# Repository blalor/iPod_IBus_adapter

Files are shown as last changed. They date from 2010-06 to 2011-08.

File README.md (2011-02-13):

iPod ↔ Sirius IBus adapter
==========================

This project is an Arduino sketch that presents an iPod or iPhone as a Sirius satellite radio receiver to the head unit (radio) in some MINI and BMW models.  It supports both simple and advanced iPod protocols.  In advanced mode, the radio shows the current track name as the channel text, and artist and album are accessible via the `INF` button.

I originally started this project because I wanted to put the radio from an '06 MINI into my '91 BMW 318is.  The MINI radio must see a valid IBus message in order to operate, otherwise it displays `-DISABLE-` on the screen and doesn't do anything at all.  Spitting out a valid IBus message every now and then would be simple.  But then I realized that iPod adapters (like the Dension ice>Link:Plus I have in my MINI) aren't cheap and most don't do everything I want, so I decided to keep going.

The end result is pretty much what I was going for, but there are some bugs to be worked out.

For more info, see the [Wiki](https://github.com/blalor/iPod_IBus_adapter/wiki/)

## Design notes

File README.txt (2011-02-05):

http://docs.hp.com/en/B3901-90007/ch05s09.html
http://www.nongnu.org/avr-libc/user-manual/group__util__setbaud.html
http://en.wikipedia.org/wiki/Circular_buffer
http://en.wikipedia.org/wiki/Operators_in_C_and_C%2B%2B
http://en.wikipedia.org/wiki/Modulo_operation

The structure of an Ibus packet is the following :
 -	Source Device ID The device which needs to send a message to another device
 -	Length The length of the packet whithout Source ID and length it-self.
 -	Destination Device ID The device which must receive the message
 -	Data The message to send to Destination ID
 -	XOR CheckSum This byte is used to check the integrity of the message. 
         The receiver will compare that value with its own computation, and
         if not equal, will reject the packet.

Messages we understand:
    src: 0x68 (radio)
        dest: 0x73 (satellite radio)
    
            cmd: 0x01 — "are you there" from radio; sent every 10s or so
            cmd: 0x3D
                data byte 1:
                    0x00 — power @todo
                    0x01 — mode @todo
                    0x02 — now @todo
                    0x03 — channel up
                    0x04 — channel down
                    0x05 — channel up and hold
                    0x06 — channel down and hold
            
                    0x08 — preset button pressed
                    0x09 — preset button press and hold
                        data byte 2 is preset number (0x01, 0x02, … 0x06)
            
                    0x0D — "m" @todo
                
                    0x0E — INF (press?) @todo
                    0x0F — INF (press and hold?) @todo
                        may need to ack 0x0E before we get 0x0F
            
                    0x14 — SAT pressed and held
                    0x15 — SAT pressed

Messages we send:
    src: 0x73 (satellite radio)
        dest: 0x68 (radio)
            data: 0x02 0x00 — poll response (sent for "are you there" from radio)
            data: 0x02 0x01 — announcement when bus activates
    
        dest: 0x68
            data byte 1: 0x3E
                all follow format
                    0x3E xx yy CC BP zz .. .. .. ..
                where:
                    xx yy — sub-command bytes
                    CC    — channel
                    B     — band nibble
                    P     — preset nibble (0-6)
                    zz    — command end byte (no idea, really)
                    ..    — text
                
                0x00 0x00 CC BP 04
                    response to power, mode
                
                // what is the 2nd byte? 0x00, 0x06, 0x07
                0x01 0x00 CC BP 04 ..
                    send text to show on head unit
                    limit of 8 or 9 characters. does not need to be refreshed
                    until it changes (I think)
                
                0x01 0x06 CC 01 01 ..
                    ack INF press. note diff't end byte, band 0, preset 1
                
                0x01 0x07 CC 01 01 ..
                    ack INF2 press. note diff't end byte, band 0, preset 1
                
                0x02 0x00 CC BP 04 '        '
                    response to channel up/down, "what now", preset and sat
                    button presses; text sent is 8 spaces

Button presses and interactions that cause ACQUIRING to (re)appear
    • pressing SAT

Other observances:
    • holding "M" seems to force a "now" command, but a single press of "M" does nothing

characters:
    ~ == ->
 \x7f == <-

== 10/14/2010 ==
so, basically "now" equates to stopping a long-running button press, and/or asking for a status update.

questions for Josh's setup:
• what does the SDRS transmit on startup?
• … when the radio is powering off (if anything(?))
• … when the radio switches modes (if anything(?))
• … in response to "now"?

• verify button presses above

• what does a single "M" push do? -- nothing
• … and does it change the operation of any other buttons? -- no
• what does a single "SAT" press do? -- changes preset bank

• what sequence of commands is sent after a channel change?
• … after an ESN request (hold "sat")

• how change band (actually, preset bank)? -- sat

mini-din 8 pinout:
1 — ipod_txd (from ipod to µC)
2 — ipod_rxd_3v3 (from µC to to ipod @ 3.3v)
3 — +5v
4 — n/c
5 — gnd
6 — line_out_r
7 — audio_gnd
8 — line_out_l

ipod connector board pinout:
1 — audio_gnd
2 — right_out
3 — left_out
4 — ipod_tx
5 — ipod_rx
6 — vcc (+5v)
7 — gnd

signal | ipod | DIN | color
-------+------+-----+--------
a_gnd  |   1  |  7  | blue
right  |   2  |  6  | green
left   |   3  |  8  | violet
txd    |   4  |  1  | black
rxd    |   5  |  2  | brown
vcc    |   6  |  3  | red
gnd    |   7  |  5  | yellow

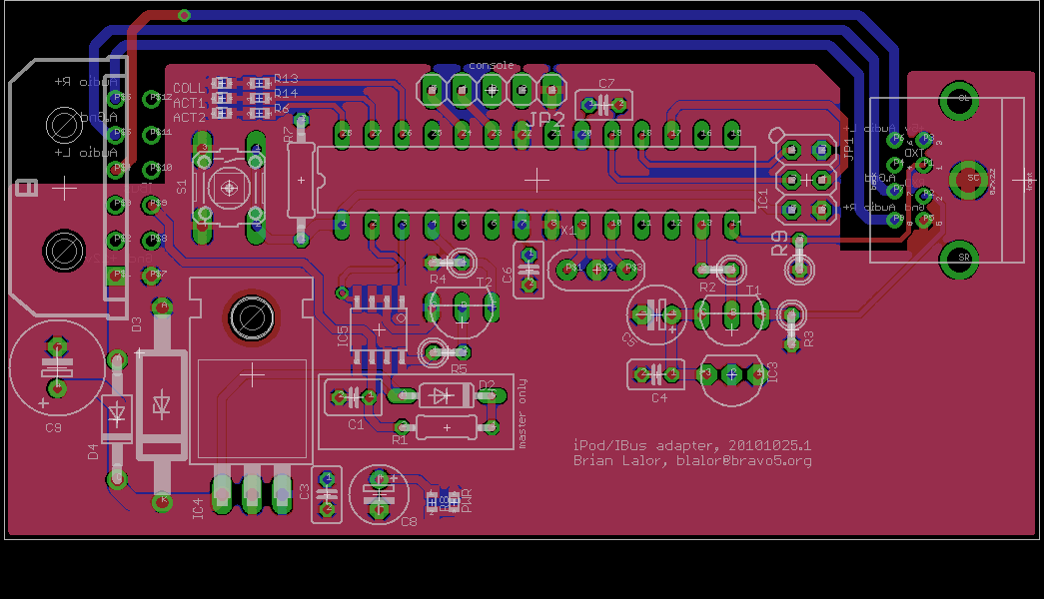
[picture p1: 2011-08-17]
eagle/ibus_adapter.brd.png

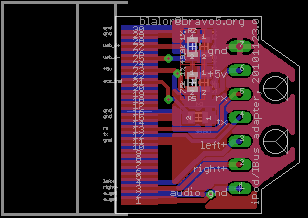
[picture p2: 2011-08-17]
eagle/ipod_connector.brd.png

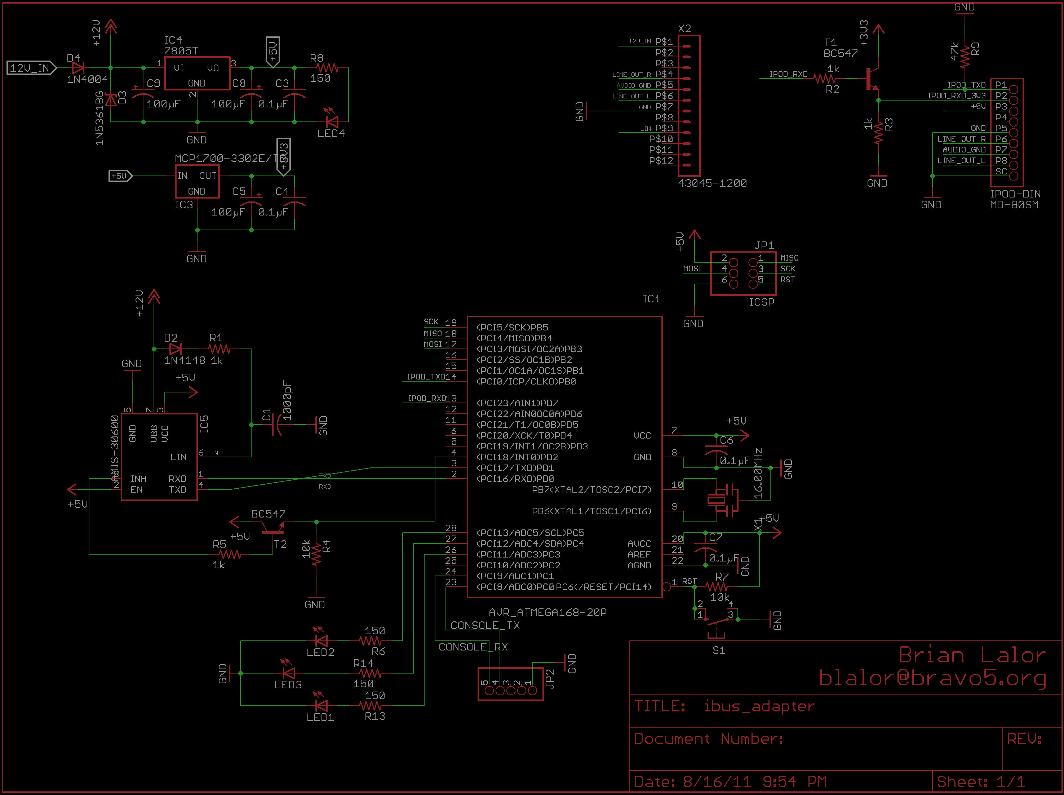
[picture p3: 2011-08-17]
eagle/ibus_adapter.sch.png

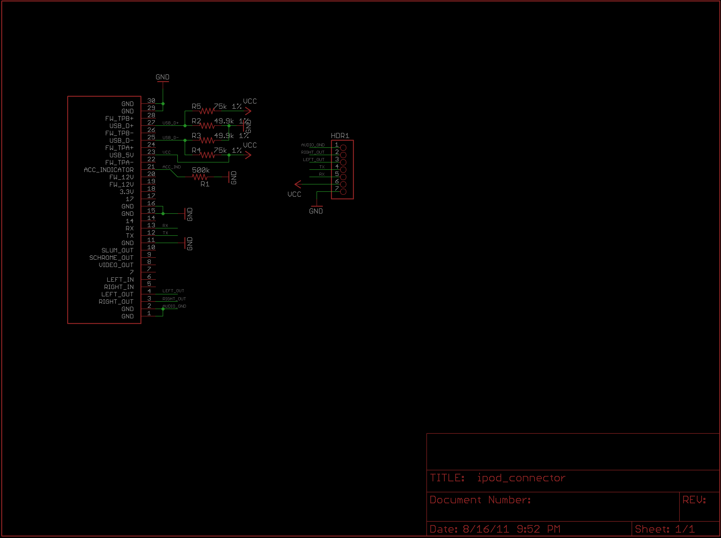
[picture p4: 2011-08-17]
eagle/ipod_connector.sch.png

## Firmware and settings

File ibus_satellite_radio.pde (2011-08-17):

/*
    The default state for an iPod when it's connected to this adapter is in
    "simple" mode; it should revert to this state whenever it's disconnected.
    
    Outstanding issues:
    • need to deal with millis() rollover
    • iPod still stops responding, occasionally
    • occasionally doesn't get metadata after iPod reconnect
    • still shows garbage at end of metadata strings after startup
    
    Current status: iPod operation appears reliable on my workbench and in the
    BMW.
 */
#define DEBUG 0
#define DEBUG_PACKET_PARSING 0
#define WICKED_VERBOSE 0

#include <string.h>
#include <stdlib.h>
#include <stdio.h>

#include <avr/wdt.h>

#include <SoftwareSerial.h>

// this is to make the Arduino include-path kludge-ifier work for iPodWrapper.h
#include <AdvancedRemote.h>

#include "iPodWrapper.h"
#include "pgm_util.h"

// @todo look into whether the preprocessor will magically convert 
// strlen("foo") -> 3
//    https://lists.linux-foundation.org/pipermail/openais/2010-March/014011.html
// … possibly; see the comment about strlen() in the section on the 
// "freestanding" compiler option:
//    http://www.nongnu.org/avr-libc/user-manual/using__tools.html#gcc_minusW
// sizeof() is compile-time?
//    http://www.avrfreaks.net/index.php?name=PNphpBB2&file=viewtopic&t=32181&start=0
#define IBUS_DATA_END_MARKER() "\xAA\xBB"
#define ibus_data(_DATA) PSTR((_DATA IBUS_DATA_END_MARKER()))

const char *IBUS_DATA_END_MARKER = IBUS_DATA_END_MARKER();

// pin mappings
#define INH_PIN 2

// RX for console is not currently supported; need special handling for
// multiple SoftwareSerial instances
#define CONSOLE_RX_PIN 14
#define CONSOLE_TX_PIN 15

#define IPOD_RX_PIN 8 // 14 on chip
#define IPOD_TX_PIN 7 // 13 on chip

/*
 * LEDs:
 *   red: missed poll from radio
 *   yellow: processing incoming IBus data
 *   green: sending IBus data
 *   
 *   yellow + green: contention/collision when sending
 */
#define LED_ERR      19 // red
#define LED_IBUS_RX  18 // yellow
#define LED_IBUS_TX  17 // green

// addresses of IBus devices
#define RAD_ADDR  0x68
#define SDRS_ADDR 0x73

// static offsets into the packet
#define PKT_SRC  0
#define PKT_LEN  1
#define PKT_DEST 2
#define PKT_CMD  3

// SDRS commands
#define SDRS_CMD_POWER          0x00 // power; not seen in Josh's car
#define SDRS_CMD_MODE           0x01 // mode
#define SDRS_CMD_NOW            0x02 // "now"
#define SDRS_CMD_CHAN_UP        0x03 // channel up
#define SDRS_CMD_CHAN_DOWN      0x04 // channel down
#define SDRS_CMD_CHAN_UP_HOLD   0x05 // channel up and hold
#define SDRS_CMD_CHAN_DOWN_HOLD 0x06 // channel down and hold
#define SDRS_CMD_START_SCAN     0x07 // "M" down and hold; start scan
#define SDRS_CMD_PRESET         0x08 // preset recall
#define SDRS_CMD_PRESET_HOLD    0x09 // preset store
#define SDRS_CMD_INF1           0x0E // INF 1st press; display artist
#define SDRS_CMD_INF2           0x0F // INF 2nd press; display song
#define SDRS_CMD_ESN_REQ        0x14 // SAT press and hold; ESN request
#define SDRS_CMD_SAT            0x15 // SAT press; preset bank change

// there may well be a protocol-imposed limit to the max value of a length
// byte in a packet, but it looks like this is the biggest we'll see in
// practice.  Use this as a sort of heuristic to determine if the incoming
// data is valid.
#define MAX_EXPECTED_LEN 64

#if MAX_EXPECTED_LEN > RX_BUFFER_SIZE
    #error MAX_EXPECTED_LEN bigger than RX_BUFFER_SIZE in HardwareSerial.h
#endif

#define TX_BUF_LEN 80
#define RX_BUF_LEN (MAX_EXPECTED_LEN + 2)

/*
prescale    target timer count  rounded timer count       (D)    (E)          % diff
       1             11110.111                11110     1440    1440.0144    -0.0010
       8              1387.888                 1388     1440    1439.8848     0.0079
      32               346.222                  346     1440    1440.9221    -0.0640
      64               172.611                  173     1440    1436.7816     0.2234
     128                85.805                   86     1440    1436.7816     0.2234
     256                42.402                   42     1440    1453.4883    -0.9366
    1024                 9.850                   10     1440    1420.4545     1.3573

@ todo
to detect the line being idle for 1.5 byte periods:
    9600-8-e-1 => 11 bits/byte
    11 * 1.5 = 16.5 bit periods

target timer count=((16000000/A2)/(960*1.5))-1 [((16000000/1)/(9600*11*1.5))-1]
rounded timer count=ROUND(target timer count '1', 0)
(D)=(16000000/A2)/(target timer count '1'+1)
(E)=(16000000/A2)/(rounded timer count '1'+1)
% diff=100-(E2*100)/D2
*/
#define CONTENTION_TIMEOUT 173        

// buffer for building outgoing packets
uint8_t tx_buf[TX_BUF_LEN];

// buffer for processing incoming packets; same size as serial buffer
uint8_t rx_buf[RX_BUF_LEN];

typedef enum __sdrs_status_enum {
    SDRS_STATUS_UNKNOWN,
    SDRS_STATUS_INACTIVE,
    SDRS_STATUS_ACTIVE
} SDRSStatusEnum;

typedef struct __sat_state {
    uint8_t channel;
    uint8_t presetBank;
    uint8_t presetNum;
    SDRSStatusEnum status; // whether we're playing or not
    boolean scanning;
} SatState;

SatState satelliteState = {1, 1, 0, SDRS_STATUS_UNKNOWN, false};

/*
 * time-keeping variables
 */
// timestamp of last poll from radio
unsigned long lastPoll; // 20s timeout

// trigger time to turn off LED
unsigned long ledOffTime; // 500ms interval

// timeout duration before giving up on a read
unsigned long readTimeout; // variable

#if DEBUG
    unsigned long lastFreeMemCheck; // 10s, or more frequently
#endif /* DEBUG */

// the 47k pull-down on the RX pin allows the iPodWrapper to detect the 
// presence of the iPod
SoftwareSerial nssIPod(
    IPOD_RX_PIN, // RX pin
    IPOD_TX_PIN, // TX pin
    false,       // inverse_logic
    false,       // disable_rx
    true         // disable_pullup
);

#if DEBUG
    SoftwareSerial nssConsole(CONSOLE_RX_PIN, CONSOLE_TX_PIN);
#endif

IPodWrapper iPodWrapper;
IPodWrapper::IPodPlayingState iPodPlayState;

// only 8 chars show on the screen for the channel display. It doesn't scroll
// on its own.
#define CHANNEL_TEXT_LENGTH 8
char channel_text_data[CHANNEL_TEXT_LENGTH + 1];
volatile boolean bus_inhibited;
boolean announcement_sent;

// this'll give me flexibility to swap between soft- and hard-ware serial 
// while developing
Print *console;

// http://www.nongnu.org/avr-libc/user-manual/group__avr__watchdog.html#_details
// http://www.nongnu.org/avr-libc/user-manual/FAQ.html#faq_startup
// http://www.nongnu.org/avr-libc/user-manual/group__largedemo.html#largedemo_code_p4
uint8_t mcusr_mirror __attribute__ ((section (".noinit")));

void get_mcusr_and_disable_wdt(void) \
  __attribute__((naked)) \
  __attribute__((section(".init3")));

void get_mcusr_and_disable_wdt(void) {
  mcusr_mirror = MCUSR;
  MCUSR = 0;
  
  wdt_disable();
}

// {{{ trackChangedHandler
void trackChangedHandler(unsigned long playlistPosition) {
    // iPod playlist position starts at 0; for aesthetics, we should start at 1
    satelliteState.channel = ((uint8_t) playlistPosition) + 1;
    update_sdrs_status();
}
// }}}

// {{{ metaDataChangedHandler
void metaDataChangedHandler() {
    update_sdrs_channel_text();
}
// }}}

// {{{ playStateChangedHandler
void playStateChangedHandler(IPodWrapper::IPodPlayingState playState) {
    // PLAY_STATE_UNKNOWN,
    // PLAY_STATE_PLAYING,
    // PLAY_STATE_PAUSED,
    // PLAY_STATE_STOPPED
    
    iPodPlayState = playState;
    
    update_sdrs_channel_text();
}
// }}}

// {{{ iPodModeChangedHandler
// for notification when mode changes between simple and advanced
void iPodModeChangedHandler(IPodWrapper::IPodMode mode) {
    // MODE_UNKNOWN,
    // MODE_SIMPLE,
    // MODE_ADVANCED

    #if DEBUG
        if (mode == IPodWrapper::MODE_UNKNOWN) {
            DEBUG_PGM_PRINTLN("[iPod] went away!");
        } else if (mode == IPodWrapper::MODE_SIMPLE) {
            DEBUG_PGM_PRINTLN("[iPod] switched to simple mode");
        } else if (mode == IPodWrapper::MODE_ADVANCED) {
            DEBUG_PGM_PRINTLN("[iPod] switched to advanced mode");
        }
    #endif
    
    update_sdrs_channel_text();
}
// }}}

#if DEBUG
    extern int __bss_end;
    extern int *__brkval;

    void printFreeMemory() {
        int free_mem;
        if ((int) __brkval == 0) {
            free_mem = ((int) &free_mem) - ((int) &__bss_end);
        } else {
            free_mem = ((int) &free_mem) - ((int)__brkval);
        }
    
        DEBUG_PGM_PRINT("free mem: ");
        DEBUG_PRINTLN(free_mem);
        lastFreeMemCheck = millis();
    }
#endif /* DEBUG */

// {{{ setup
void setup() {
    #if DEBUG
        // RX not supported; see comment near CONSOLE_RX_PIN define
        nssConsole.begin(115200);
        
        console = &nssConsole;
        
        printFreeMemory();
        
        if (mcusr_mirror & _BV(PORF))  DEBUG_PGM_PRINTLN("==== power-on reset ====");
        if (mcusr_mirror & _BV(EXTRF)) DEBUG_PGM_PRINTLN("==== external reset ====");
        if (mcusr_mirror & _BV(BORF))  DEBUG_PGM_PRINTLN("==== brown-out reset ====");
        if (mcusr_mirror & _BV(WDRF))  DEBUG_PGM_PRINTLN("==== watchdog reset ====");
    #endif /* DEBUG */
    
    pinMode(LED_ERR, OUTPUT);
    pinMode(LED_IBUS_TX, OUTPUT);
    pinMode(LED_IBUS_RX, OUTPUT);
    
    pinMode(INH_PIN, INPUT);
    
    // indicate setup is underway; green flashes for IBus TX
    digitalWrite(LED_IBUS_RX, HIGH);
    
    announcement_sent = false;
    
    // zero-out channel text buffer, including trailing nul
    memset(channel_text_data, 0, CHANNEL_TEXT_LENGTH + 1);
    
    // Set up timer2 at Fcpu/64 for contention detection. Must be done before 
    // any IBus serial activity!
    //     CS22:1, CS21:0, CS20:0
    TCCR2B = _BV(CS22); // ~_BV(CS21) | ~_BV(CS20);
    
    // set up serial for IBus; 9600,8,E,1
    Serial.begin(9600);
    UCSR0C |= _BV(UPM01); // even parity
    
    // start the watchdog timer w/ 4s timeout
    wdt_enable(WDTO_4S);

    // test to make sure the bus is alive; if it isn't, shut down (but do not
    // reconfigure) the USART
    
    if (digitalRead(INH_PIN) == LOW) {
        // bus is inhibited
        DEBUG_PGM_PRINTLN("[IBus] bus is inhibited");
    } else {
        DEBUG_PGM_PRINTLN("[IBus] bus is alive");
    }
    
    // can't do anything while the bus is asleep.
    // bus_inhibited = true;
    // while (bus_inhibited) {
    //     wdt_reset();
    //     configureForBusInhibition();
    // }
    // 
    // // enable INT0
    // // @todo use this interrupt to wake the µC from sleep
    // attachInterrupt(0, configureForBusInhibition, CHANGE);    
    
    // baud rate for iPodSerial
    // not having much luck with 38,400; maybe related to my "buffer"
    // implementation (emitter-follower)?  19,200 works in both simple and
    // advanced modes, however, even with the iPhone, it seems!
    
    nssIPod.begin(19200);
    // nssIPod.begin(iPodSerial::IPOD_SERIAL_RATE);
    
    iPodPlayState = IPodWrapper::PLAY_STATE_UNKNOWN;
    
    // for notification when the currently-playing track changes
    iPodWrapper.setTrackChangedHandler(trackChangedHandler);
    
    iPodWrapper.setMetaDataChangedHandler(metaDataChangedHandler);
    iPodWrapper.setPlayStateChangedHandler(playStateChangedHandler);
    
    // for notification when mode changes between simple and advanced
    iPodWrapper.setModeChangedHandler(iPodModeChangedHandler);

    iPodWrapper.init(&nssIPod, IPOD_RX_PIN);
    
    iPodWrapper.setAdvanced();
    
    // send SDRS announcement
    DEBUG_PGM_PRINTLN("[IBus] sending initial announcement");
    send_sdrs_device_ready_after_reset();
    
    #if DEBUG
        printFreeMemory();
    #endif /* DEBUG */
    
    for (int i = 0; i < 3; i++) {
        wdt_reset();
        
        digitalWrite(LED_ERR, HIGH);
        digitalWrite(LED_IBUS_RX, HIGH);
        digitalWrite(LED_IBUS_TX, HIGH);
        delay(250);
        digitalWrite(LED_ERR, LOW);
        digitalWrite(LED_IBUS_RX, LOW);
        digitalWrite(LED_IBUS_TX, LOW);
        delay(250);
    }
}
// }}}

// {{{ loop
void loop() {
    wdt_reset();
    
    if (millis() > ledOffTime) {
        digitalWrite(LED_IBUS_TX, LOW);
    }
    
    iPodWrapper.update();
    
    #if DEBUG
        if (millis() > (lastFreeMemCheck + 10000L)) {
            printFreeMemory();
        }
    #endif /* DEBUG */
    
    // can't do anything while the bus is asleep.
    if (bus_inhibited) {
        // @todo flash leds?
    } else {
        if ((lastPoll + 20000L) < millis()) {
            DEBUG_PGM_PRINTLN("[IBus] haven't seen a poll in a while; we're dead to the radio");
            digitalWrite(LED_ERR, HIGH);
            
            send_sdrs_device_ready_after_reset();
            lastPoll = millis();
            
            digitalWrite(LED_ERR, LOW);
        }
        
        process_incoming_data();
    }
}
// }}}

// {{{ disableSerialReceive
inline void disableSerialReceive() {
    UCSR0B &= ~(_BV(RXEN0) | _BV(RXCIE0));
}
// }}}

// {{{ enableSerialReceive
inline void enableSerialReceive() {
    // @todo still (usually?) getting 2 bytes in the RX buffer after 
    //       transmitting, even with RX turned off
    
    // wait for TX buffer to flush (while TX is not complete)
    while (! (UCSR0A & _BV(TXC0)));
            
    UCSR0B |= _BV(RXEN0) | _BV(RXCIE0);
}
// }}}

// {{{ configureForBusInhibition
/*
 * If the I-Bus is alive, enable the RX hardware.  If it's not, shut down
 * the RX hardware and flush the buffer.
 */
void configureForBusInhibition() {
    // bus is uninhibited (alive) when PORTD2 is high
    bus_inhibited = (digitalRead(INH_PIN) == LOW);
    
    if (bus_inhibited) {
        // shutdown the receive circuitry, flush any remaining data
        disableSerialReceive();
        Serial.flush();
    } else {
        // bus is now enabled; restart USART
        enableSerialReceive();
    }
}
// }}}

// {{{ process_incoming_data
boolean process_incoming_data() {
    /*
    The serial reading is pretty naive. If we start reading in the middle of
    a packet transmission, the checksum validation will fail. All data
    received up to that point will be lost. It's expected that this loop will
    eventually synchronize with the stream during a lull in the conversation,
    where all available and "invalid" data will have been consumed.
    */
    
    boolean found_message = false;
    
    uint8_t bytes_availble = Serial.available();
    
    if (bytes_availble) {
        digitalWrite(LED_IBUS_RX, HIGH);

        #if DEBUG && DEBUG_PACKET_PARSING
            DEBUG_PGM_PRINT("[pkt] buf contents: ");
            for (int i = 0; i < bytes_availble; i++) {
                DEBUG_PRINT(Serial.peek(i), HEX);
                DEBUG_PGM_PRINT(" ");
            }
            DEBUG_PRINTLN();
        #endif
    }
    
    // filter out packets from sources we don't care about
    // I don't like this solution at all, but until I can implement a timer to 
    // reset in the RX interrupt I think this will at least avoid getting 
    // stuck waiting for enough data to arrive
    if (bytes_availble && (Serial.peek(PKT_SRC) != RAD_ADDR) && (Serial.peek(PKT_SRC) != SDRS_ADDR)) {
        DEBUG_PGM_PRINTLN("[IBus] dropping byte from unknown source");
        Serial.remove(1);
    }
    // need at least two bytes to a packet, src and length
    else if (bytes_availble > 2) {
        // length of the data
        uint8_t data_len = Serial.peek(PKT_LEN);

        #if DEBUG && DEBUG_PACKET_PARSING
            DEBUG_PGM_PRINT("[pkt] have ");
            DEBUG_PRINT(bytes_availble, DEC);
            DEBUG_PGM_PRINTLN(" bytes available");
        
            DEBUG_PGM_PRINT("[pkt] packet length is ");
            DEBUG_PRINTLN(data_len, DEC);
        #endif
        
        if (
            (data_len == 0)                || // length cannot be zero
            (data_len >= MAX_EXPECTED_LEN)    // we don't handle messages larger than this
        ) {
            DEBUG_PGM_PRINTLN("[IBus] invalid packet length");
            
            #if DEBUG && DEBUG_PACKET_PARSING
                     if (data_len == 0) DEBUG_PGM_PRINTLN("[pkt] length cannot be zero");
                else if (data_len >= MAX_EXPECTED_LEN) DEBUG_PGM_PRINTLN("[pkt] we don't handle messages larger than this");
            #endif
            
            Serial.remove(1);
        }
        else {
            // length of entire packet including source and length
            uint8_t pkt_len = data_len + 2;

            // index of the checksum byte
            uint8_t chksum_ind = pkt_len - 1;
            
            #if DEBUG && DEBUG_PACKET_PARSING
                DEBUG_PGM_PRINT("[pkt] checksum at index ");
                DEBUG_PRINT(chksum_ind, DEC);
                DEBUG_PGM_PRINT(": ");
                DEBUG_PRINTLN(Serial.peek(chksum_ind), HEX);

                DEBUG_PGM_PRINT("[pkt] need at least ");
                DEBUG_PRINT(pkt_len, DEC);
                DEBUG_PGM_PRINTLN(" bytes for complete packet");
            #endif

            // ensure we've got enough data in the buffer to comprise a
            // complete packet
            if (bytes_availble >= pkt_len) {
                // yep, have enough data
                readTimeout = 0;

                // verify the checksum
                int calculated_chksum = 0;
                for (int i = 0; i < chksum_ind; i++) {
                    calculated_chksum ^= Serial.peek(i);
                }

                if (calculated_chksum == Serial.peek(chksum_ind)) {
                    found_message = true;
                    
                    // valid checksum

                    #if DEBUG_PACKET_PARSING
                        DEBUG_PGM_PRINT("[pkt] received pkt ");
                    #endif

                    // read packet into buffer and dispatch
                    for (int i = 0; i < pkt_len; i++) {
                        rx_buf[i] = Serial.read();

                        #if DEBUG_PACKET_PARSING
                            DEBUG_PRINT(rx_buf[i], HEX);
                            DEBUG_PGM_PRINT(" ");
                        #endif
                    }

                    #if DEBUG_PACKET_PARSING
                        DEBUG_PRINTLN();
                    #endif
                    
                    #if WICKED_VERBOSE
                        DEBUG_PGM_PRINT("[IBus] packet from ");
                        DEBUG_PRINTLN(rx_buf[PKT_SRC], HEX);
                    #endif
                    
                    dispatch_packet(rx_buf);
                }
                else {
                    // invalid checksum; drop first byte in buffer and try
                    // again
                    DEBUG_PGM_PRINTLN("[IBus] invalid checksum");
                    Serial.remove(1);
                }
            } // if (bytes_availble …)
            else {
                // provide a timeout mechanism; expire if needed bytes 
                // haven't shown up in the expected time.
                
                if (readTimeout == 0) {
                    // (10 bits/byte) => 1.042ms/byte; add a 20% fudge factor
                    readTimeout = ((125 * ((pkt_len - bytes_availble) + 1)) / 100);
                    
                    #if DEBUG && DEBUG_PACKET_PARSING
                        DEBUG_PGM_PRINT("[pkt] read timeout: ");
                        DEBUG_PRINTLN(readTimeout, DEC);
                    #endif
                    
                    readTimeout += millis();
                }
                else if (millis() > readTimeout) {
                    DEBUG_PGM_PRINTLN("[IBus] dropping packet due to read timeout");
                    readTimeout = 0;
                    Serial.remove(1);
                }
            }
        }
    } // if (bytes_availble  >= 2)
    
    digitalWrite(LED_IBUS_RX, LOW);

    return found_message;
}
// }}}
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

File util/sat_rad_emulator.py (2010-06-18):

#!/usr/bin/env python
# encoding: utf-8
"""
untitled.py

Created by Brian Lalor on 2010-04-21.
Copyright (c) 2010 __MyCompanyName__. All rights reserved.
"""

import sys
import os
from pprint import pprint 
import string
import serial
import time
import cPickle as pickle

# alextronic: http://translate.google.com/translate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
# http://ibus.stuge.se/IBus_Devices
id_map = {
    0x00 : 'Broadcast',
    0x18 : 'CDW - CDC CD-Player',
    0x30 : 'SES (voice)', # alextronic
    0x3B : 'NAV/GT Navigation/Videomodule (graphics driver, navigation)',
    0x3F : 'DIS (ext. diagnostic system)', # alextronic
    0x43 : 'MenuScreen',
    0x44 : '?????',
    0x50 : 'MFL Multi Functional Steering Wheel Buttons',
    0x60 : 'PDC Park Distance Control',
    0x68 : 'RAD Radio',
    0x6A : 'DSP Digital Sound Processor',
    0x73 : 'SDRS',
    0x7F : 'GPS',
    0x80 : 'IKE Instrument Kombi Electronics',
    #0xA8 : '?????',
    0xBB : 'TV Module',
    0xBF : 'GLO global broadcast', # 'LCM Light Control Module, or maybe broadcast?',
    0xC0 : 'MID Multi-Information Display Buttons',
    0xC8 : 'TEL Telephone',
    0xD0 : 'Navigation Location/Data', # alextronic
    0xE7 : 'OBC TextBar',
    #0xE8 : '?????',
    0xED : 'Lights, Wipers, Seat Memory',
    0xF0 : 'BMB Board Monitor Buttons',
    0xFF : 'Broadcast',
    
    ## seen on my MINI
    0xA4 : 'ABM Airbag',
    0x5B : 'IHK Integrated heating, A/C',
}

sat_channel = 1
sat_band = 1
sat_preset = 1

# The structure of an Ibus packet is the folllowing :
## -	Source Device ID The device which needs to send a message to another device
## -	Length The length of the packet whithout Source ID and length it-self.
## -	Destination Device ID The device which must receive the message
## -	Data The message to send to Destination ID
## -	XOR CheckSum This byte is used to check the integrity of the message. 
##         The receiver will compare that value with its own computation, and
##         if not equal, will reject the packet.

def make_printable(x):
    if x in string.printable:
        return x
    else:
        return "."
    



## all args are 2-char hex strings; data is space-separated
def make_packet(src, dest, data, text = ""):
    print 'make_packet(%s, %s, %s, %s)' % (src, dest, data, text)
    
    # add two for length and checksum bytes
    data_len = len(data.split()) + len(text) + 2
    
    packet = [src, '%.2X' % (data_len,), dest]
    packet.extend(data.split())
    print 'packet:', packet
    bin_packet = "".join([chr(int(x, 16)) for x in packet])
    #print bin_packet
    bin_packet += text
    #print bin_packet
    
    chksum = 0
    for b in bin_packet:
        chksum ^= ord(b)
    
    bin_packet += chr(chksum)
    #print " ".join(['%.2X' % (ord(b),) for b in bin_packet])
    # ser.write("".join([chr(int(x, 16)) for x in "73 04 FF 02 01 8B".split()]))
    return bin_packet    


def display_packet_data(packet, ser):
    whole_hex_packet = " ".join(['%.2X' % (b,) for b in packet])
    global sat_channel
    global sat_band
    global sat_preset
    
    ## http://web.comhem.se/bengt-olof.swing/stwbuttons.htm
    buttons = {
        '50 04 68 32 10 1E' : '<-> press',
        '50 04 68 32 11 1F' : '<+> press',
        '50 04 68 32 30 3E' : '<-> release',
        '50 04 68 32 31 3F' : '<+> release',
        
        '50 04 68 3B 01 06' : '<next> press',
        '50 04 68 3B 11 16' : '<next> 1 second',
        '50 04 68 3B 21 26' : '<next> release',
        
        '50 04 68 3B 08 0F' : '<previous> press',
        '50 04 68 3B 18 1F' : '<previous> 1 second',
        '50 04 68 3B 28 2F' : '<previous> release',
        
        '50 04 C8 3B 80 27' : '<R/T>',
        '50 04 C8 3B 80 27' : '<voice> press',
        '50 04 C8 3B 90 37' : '<voice> hold',
        '50 04 C8 3B A0 07' : '<voice> release',
    }
    
    cd_cmd = " ".join(['%.2X' % (b,) for b in packet[3:-6]])
    
    # 18 0a 68 39 02 09 00 3f 00 06 22 53
    #          39 02 09                     -- cmd prefix
    #                   00                  -- literal
    #                      3f               -- populated CDs (bitmask)
    #                         00            -- literal
    #                            06 22      -- disc, track
    #                                  53
    # command prefix, disc, track, checksum
    cd_changer = {
        '39 00 02' : 'CD and Track Status Not Playing Response',
        '39 00 09' : 'CD and Track Status Playing Response',
        '39 02 09' : 'Track Start Playing',
        '39 03 09' : 'CD Status Scan Forward',
        '39 04 09' : 'CD Status Scan Backward',
        '39 07 09' : 'Track End Playing',
        '39 08 09' : 'CD # dd',
        '39 08 09' : 'CD Seeking',
        '39 08 09' : 'Loaded CD 1,2,3,4,5,6',
        '39 08 09' : 'Track # tt',
    }
    
    sdrs_rx = {
        'sPoll'  : '01',    # 68 03 73 , chksum  19
        
        'sPower' : '3D 00 00', # 68 05 73 , chksum  23
        'sMode'  : '3D 01 00', # 68 05 73 , chksum  22
        'sNow'   : '3D 02 00', # 68 05 73 , chksum  21
        'sUp'    : '3D 03 00', # 68 05 73 , chksum  20
        'sDown'  : '3D 04 00', # 68 05 73 , chksum  27
        'sUpH'   : '3D 05 00', # 68 05 73 , chksum  26
        'sDownH' : '3D 06 00', # 68 05 73 , chksum  25
        
        
        'sPre1'  : '3D 08 01', # 68 05 73 , chksum  2A
        'sPre2'  : '3D 08 02', # 68 05 73 , chksum  29
        'sPre3'  : '3D 08 03', # 68 05 73 , chksum  28
        'sPre4'  : '3D 08 04', # 68 05 73 , chksum  2F
        'sPre5'  : '3D 08 05', # 68 05 73 , chksum  2E
        'sPre6'  : '3D 08 06', # 68 05 73 , chksum  2D
        
        'sPreH1' : '3D 09 01', # 68 05 73 , chksum  2B
        'sPreH2' : '3D 09 02', # 68 05 73 , chksum  28
        'sPreH3' : '3D 09 03', # 68 05 73 , chksum  29
        'sPreH4' : '3D 09 04', # 68 05 73 , chksum  2E
        'sPreH5' : '3D 09 05', # 68 05 73 , chksum  2F
        'sPreH6' : '3D 09 06', # 68 05 73 , chksum  2C
        
        'sM'     : '3D 0D 00', # 68 05 73 , chksum  2E
        'sInf1'  : '3D 0E 00', # 68 05 73 , chksum  2D
        'sInf2'  : '3D 0F 00', # 68 05 73 , chksum  2C
        
        'sSat2?' : '3D 14 00', # sent for press-and-hold of SAT
        'sSat'   : '3D 15 00', # 68 05 73 , chksum  36
    }
    
    sdrs_tx = {
        'power': "73 10 68 3e 00 00 01 11 04 70 6f 77 65 72 20 20 20 7e",
    }
    ## if whole_hex_packet in buttons:
    ##     print buttons[whole_hex_packet]
    ## 
    ## elif cd_cmd in cd_changer:
    ##     print "%s: disc %X, track %X, CDs loaded %s" % (cd_changer[cd_cmd],
    ##                                                     packet[-3],
    ##                                                     packet[-2],
    ##                                                     bin(packet[7]))
    ##     
    ## 
    ## elif (packet[1] == 3) and (packet[3] == 1):
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

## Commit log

2010-06-16 The Sirius receiver emulation is working pretty reliably, now. Instead of using my own "MyHardwareSerial" class, I decided to just patch HardwareSerial.{cpp,h} that's included with the standard Ardui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
2010-06-18 Checkpoint commit. I think for this commit I largely just changed the static strings to progmem strings, but a lot of supporting code had to go along with that…
2010-10-07 Checkpoint commit. Tweaking data handling, preparing to handle sleeping bus. Didn't even attempt to compile this…
    [ibus_satellite_radio.pde]
2010-10-12 adding debug output indicating why the microcontroller was reset
    [ibus_satellite_radio.pde]
2010-10-12 Checkpoint commit. This seems to be working much more reliably, now. No longer getting stuck waiting for data to show up. One problem's still bugging me, however. Despite turning off the RX hardware 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
    [ibus_satellite_radio.pde, watch_serial.py]
2010-10-16 reimplemented request/response according to data captured from Josh's car. Not complete (missing scan, fast channel up/down) but it seems to work fine!
    [ibus_satellite_radio.pde]
2010-10-19 checkpoint commit; not sure what changed...
    [ibus_adapter.brd, ibus_adapter.sch]
2010-10-22 adding first cut at a board for the inside of the iPod connector housing
    [ipod_connector.brd, ipod_connector.sch]
2010-10-22 checkpoint; sending to Laen for a sanity check
    [ipod_connector.brd]
2010-10-26 preparing iPod/IBus board for production
    [ibus_adapter.brd, ibus_adapter.sch, ipod_connector.brd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]
2010-10-26 preparing 20101025.0; sending to Laen
    [ibus_adapter.brd, ipod_connector.brd]
2010-10-26 increasing text ratio; labelled 20101025.1
    [ibus_adapter.brd, ipod_connector.brd]
2010-10-26 added parts for iPod connector
2010-10-27 updated BOM with parts from iPod connector
2010-11-14 Changed defines for LED and NSS pins to match hardware layout for first board rev.
2010-11-24 tweaking board dimensions; preparing for panelization for home
    [ipod_connector.brd]
2010-11-30 NOT COMPILED
    • Roughing in Advanced Remote support.
    • Attempted to make the SDRS IBus packet transmissions more readable.
    • Enabled the "scanning" ([SC]) flag for status and channel updates. Not sure
    what I'll do with that, yet…
    NOT COMPILED
2010-12-01 this is a mess. can't get the ipod to cooperate in advanced mode. sort of working, but not all messages appear to be getting through…
2010-12-02 code compiles and the iPodWrapper seems to work! needed some cleanup to cope with my lack of C++ chops. ibus_satellite_radio.pde still not tested.
    IMPORTANT: NewSoftSerial doesn't work well with two active NSS objects. Need
    to modify it to support send-only for console instance! Otherwise, that becomes
    the "active" object whenever debug output is sent and we lose the iPod.
    • pointers to member functions don't really work; implemented listener class.
    need to hack iPodSerial AdvancedRemote class to match
    • I think I figured out how polling should work in advanced mode.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
    [ibus_satellite_radio.pde]
2011-01-26 Checkpoint commit
    Lots of small updates to go along with the iPodWrapper. Generally seems to
    work quite well. Some small things to fix, but looks pretty solid.
    [ibus_satellite_radio.pde]
2011-01-26 Removing obsolete patch
    Now depend on fork of Arduino source and (New)SoftSerial.
2011-01-26 Code cleanup
    • better semantics for LEDs
    • wiping cached metadata when switching to simple mode (calling reset())
    [ibus_satellite_radio.pde]
2011-01-27 additional tweaks
    • better handling of initial playlist position update
    • shortened text for channel name to only the 8 characters shown
    [ibus_satellite_radio.pde]
2011-02-04 Replacing digitalRead & digitalWrite
    Using "port & bitmask" method, instead. Faster than the Arduino functions.
2011-02-05 Adding pin mapping for iPod serial cable
    … including internal wire colors for the cables I'm using right now.
2011-02-08 Improving iPod mode switching logic
    Broken flow: simple mode commands getting sent in advanced mode
    --> 2640ms: <ff 55 03 00 01 02 fa > [00] (01 02) Switch to simple
    --> 63ms: <ff 55 03 00 01 04 f8 > [00] (01 04) Switch to advanced
    --> 0ms: <ff 55 03 04 00 1c dd > [04] (00 1c) Get time and status info
    --> 0ms: <ff 55 04 02 00 00 02 f8 > [02] (00 00) Pause
    --> 47ms: <ff 55 03 02 00 00 fb > [02] (00 00) Button released
    <-- 2752ms: <ff 55 0c 04 00 1d 00 03 94 87 00 00 c5 db 02 13> [04] (00 1d) time and status info -- trk len: 3:54.631, elapsed: 0:50.651,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
2011-02-08 Reverting 1d3ee9094f6c8b0632fdcce564293a84f339bc2b
    I think I did something wrong with a rebase…
    [ibus_satellite_radio.pde]
2011-02-08 Checkpoint commit: mostly reliable?
    iPod operation appears reliable on my workbench and in the BMW. Try not to
    mess with anything and see if it continues to be reliable.
    Based on what I'm seeing on the oscilloscope, the serial timing isn't very
    accurate. Bit widths at 19200 should be 52.08µs but are 56µs instead, which
    makes the actual baud rate 17857, or about 7% off. The iPod seems to adapt to
    this perfectly, but it still isn't correct.
    [ibus_satellite_radio.pde]
2011-03-26 labelling signal names
    [ipod_connector.brd]
2011-03-26 Adding R9 pull-down for iPod presence detection
    47k pull-down for IPOD_TXD allow the line to go low when the iPod's not
    attached, allowing for a test with PB0 to see if the iPod's there or not.
    [ibus_adapter.brd, ibus_adapter.sch]
